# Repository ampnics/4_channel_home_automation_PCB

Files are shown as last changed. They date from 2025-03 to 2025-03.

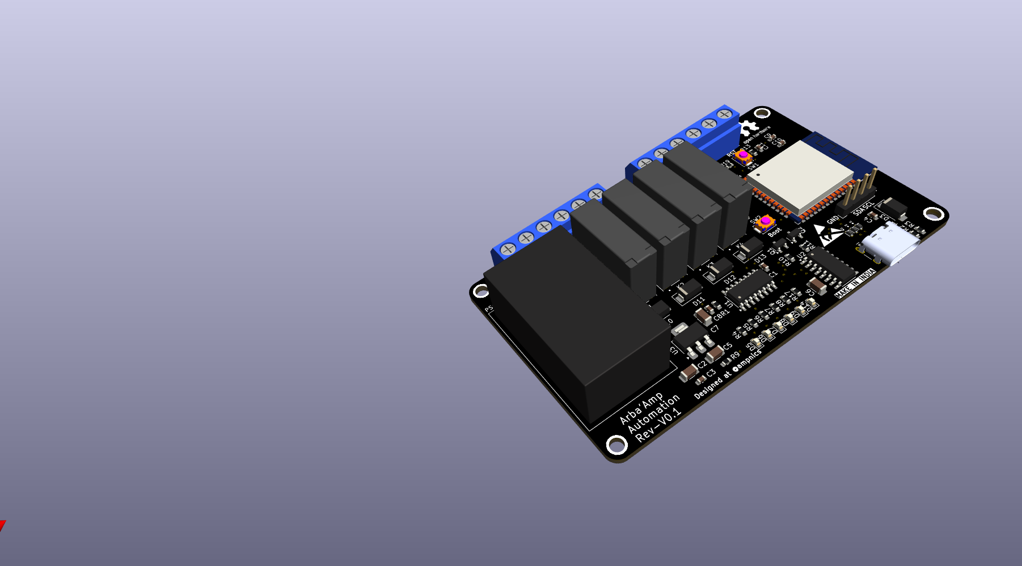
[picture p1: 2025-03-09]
Arbaa_Amp_V0.1/Docs/Img.png

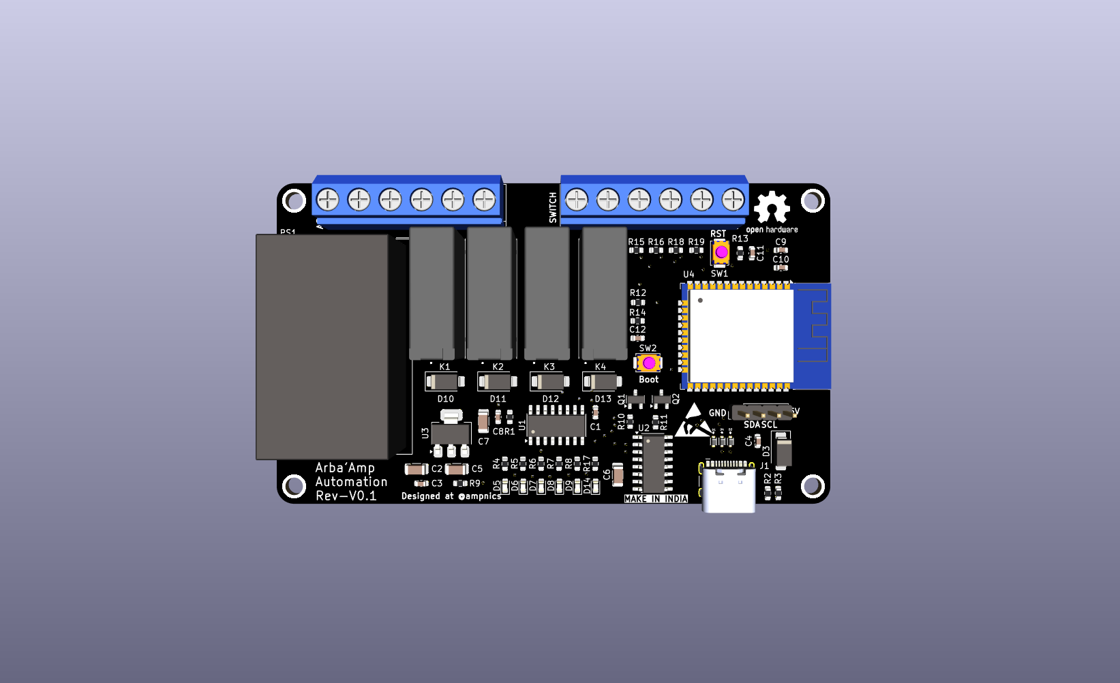
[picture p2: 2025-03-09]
Arbaa_Amp_V0.1/Docs/Top_img.png

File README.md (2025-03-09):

4-Channel Home Automation with ESP32 PCB
This project is a 4-channel home automation system based on the ESP32, designed to control electrical appliances via Wi-Fi, 
MQTT, or a mobile app. The custom PCB integrates relays, optoisolated inputs, and an efficient power supply for reliable operation.

Features

✔ ESP32-based Wi-Fi control (supports web server & MQTT).

✔ 4-Channel relay output for appliance control.

✔ Optoisolated inputs for safe external switch connections.

✔ Onboard buck converter (AC/DC to 5V) for efficient power.

✔ Compact PCB design for easy enclosure integration.

Hardware Overview

1️⃣ Components Used:

ESP32-WROOM-32 (Wi-Fi + Bluetooth MCU)

4 x Relays (5V or 12V, SPDT)

Optocouplers for switch inputs

AC to DC Buck Converter (HLK-PM03 or equivalent)

Screw terminals for easy wiring

Status LEDs for each relay & power indicator

2️⃣ PCB Design Details:

Designed in KiCad

2-layer PCB for cost efficiency

Proper relay isolation from low-voltage ESP32

Wide power traces for relay switching

It is open source design by Md Ammar Maniyar for @ampnics

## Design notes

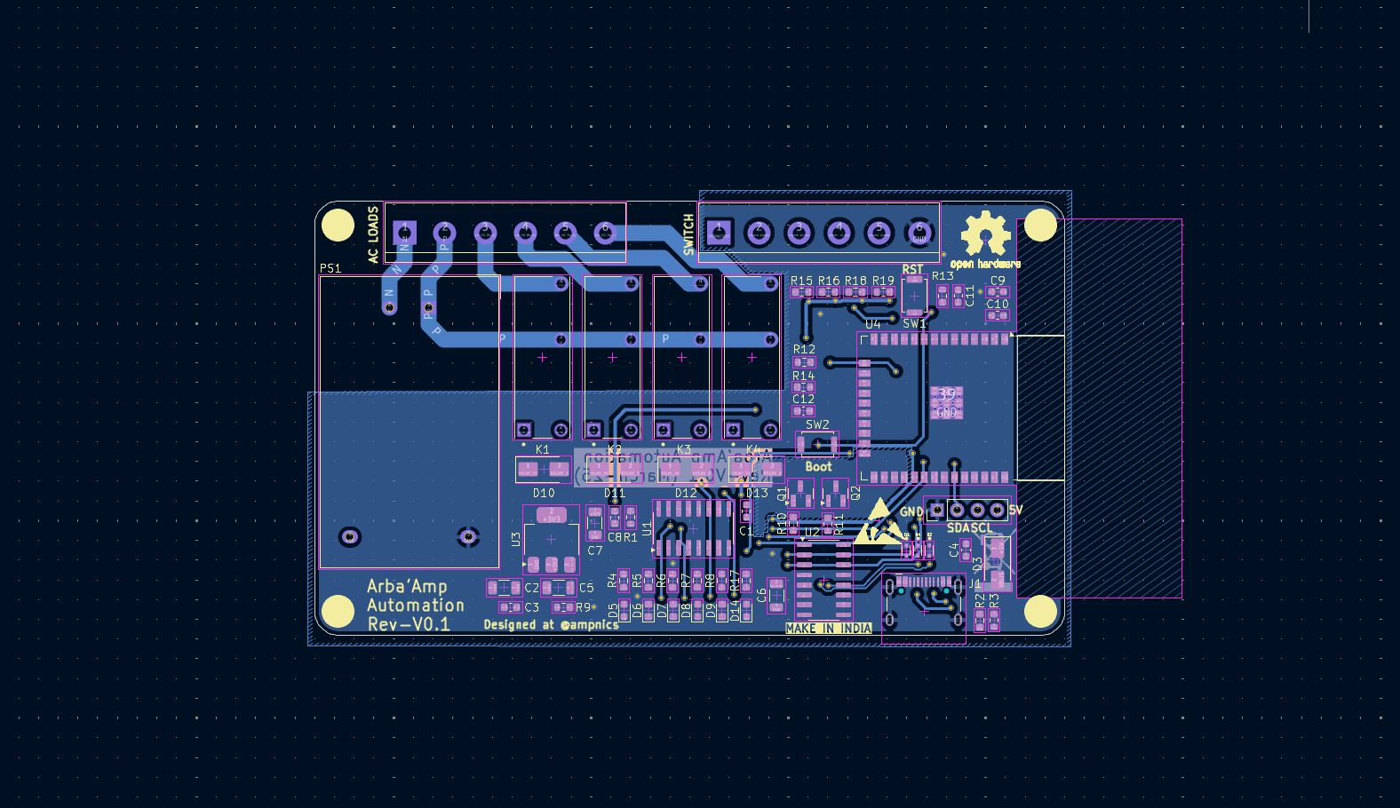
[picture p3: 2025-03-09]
Arbaa_Amp_V0.1/Docs/Bottom_layout.png

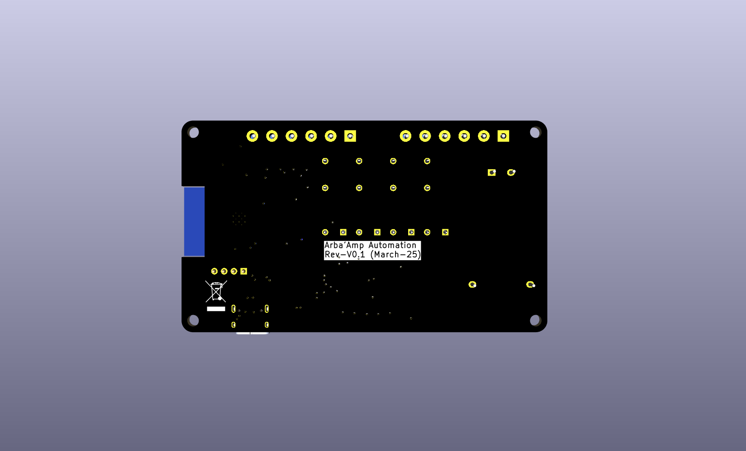
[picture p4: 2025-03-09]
Arbaa_Amp_V0.1/Docs/Bottom_img.png

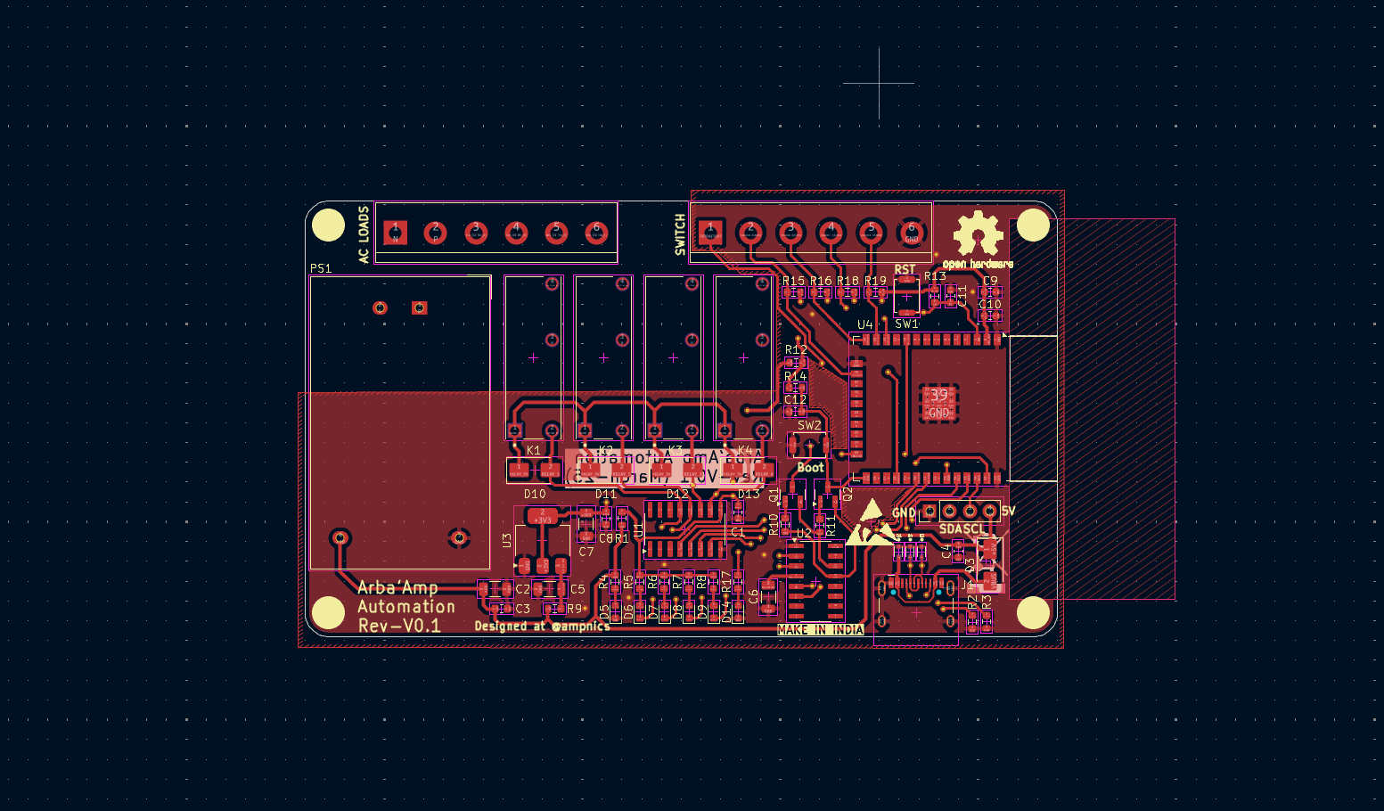
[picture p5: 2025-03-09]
Arbaa_Amp_V0.1/Docs/top_layout.png

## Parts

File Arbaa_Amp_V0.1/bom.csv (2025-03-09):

Reference | Qty | Value | DNP | Exclude from BOM | Exclude from Board | Footprint | Datasheet
C1,C3,C8 | 3 | 0.1uF |  |  |  | Capacitor_SMD:C_0603_1608Metric | ~
C2,C5,C7 | 3 | 10uF |  |  |  | Capacitor_SMD:C_1206_3216Metric | ~
C4 | 1 | 10uF/25V |  |  |  | Capacitor_SMD:C_0603_1608Metric | ~
C6 | 1 | 10nf |  |  |  | Capacitor_SMD:C_1206_3216Metric | ~
C9,C10,C11,C12 | 4 | 0.1uf |  |  |  | Capacitor_SMD:C_0603_1608Metric | ~
D1,D2,D4 | 3 | LESD5D5.0CT1G |  |  |  | LESD5D5.0CT1G:TVS_LESD5D5.0CT1G
D3,D10,D11,D12,D13 | 5 | SS34 |  |  |  | Diode_SMD:D_SMA | https://www.vishay.com/docs/88751/ss32.pdf
D5,D6,D7,D8,D9,D14 | 6 | LED |  |  |  | LED_SMD:LED_0603_1608Metric | ~
J1 | 1 | USB_C_Receptacle_USB2.0_16P |  |  |  | Connector_USB:USB_C_Receptacle_HCTL_HC-TYPE-C-16P-01A | https://www.usb.org/sites/default/files/documents/usb_type-c.zip
J2,J3 | 2 | Screw_Terminal_01x06 |  |  |  | TerminalBlock:TerminalBlock_bornier-6_P5.08mm | ~
J4 | 1 | Conn_01x04_Pin |  |  |  | Connector_PinHeader_2.54mm:PinHeader_1x04_P2.54mm_Vertical | ~
K1,K2,K3,K4 | 4 | HF46F_005-HS1 |  |  |  | HF46F_005-HS1:RELAY_HF46F_005-HS1
PS1 | 1 | HLK-PM01 |  |  |  | Converter_ACDC:Converter_ACDC_Hi-Link_HLK-PMxx | https://h.hlktech.com/download/ACDC%E7%94%B5%E6%BA%90%E6%A8%A1%E5%9D%973W%E7%B3%BB%E5%88%97/1/%E6%B5%B7%E5%87%8C%E7%A7%913W%E7%B3%BB%E5%88%97%E7%94%B5%E6%BA%9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
Q1,Q2 | 2 | SS8050 |  |  |  | Package_TO_SOT_SMD:SOT-23 | http://www.secosgmbh.com/datasheet/products/SSMPTransistor/SOT-23/SS8050.pdf
R1,R9,R12 | 3 | 0E |  |  |  | Resistor_SMD:R_0603_1608Metric | ~
R2,R3 | 2 | 5.1K |  |  |  | Resistor_SMD:R_0603_1608Metric | ~
R4,R5,R6,R7,R8,R17 | 6 | 2K2 |  |  |  | Resistor_SMD:R_0603_1608Metric | ~
R10,R11,R14 | 3 | 10k |  |  |  | Resistor_SMD:R_0603_1608Metric | ~
R13,R15,R16,R18,R19 | 5 | 10K |  |  |  | Resistor_SMD:R_0603_1608Metric | ~
SW1,SW2 | 2 | SW_Push |  |  |  | Button_Switch_SMD:SW_Push_SPST_NO_Alps_SKRK | ~
U1 | 1 | ULN2003A |  |  |  | Package_SO:SOIC-16_3.9x9.9mm_P1.27mm | http://www.ti.com/lit/ds/symlink/uln2003a.pdf
U2 | 1 | CH340C |  |  |  | Package_SO:SOIC-16_3.9x9.9mm_P1.27mm | https://datasheet.lcsc.com/szlcsc/Jiangsu-Qin-Heng-CH340C_C84681.pdf
U3 | 1 | AMS1117-3.3 |  |  |  | Package_TO_SOT_SMD:SOT-223-3_TabPin2 | http://www.advanced-monolithic.com/pdf/ds1117.pdf
U4 | 1 | ESP32-WROOM-32 |  |  |  | RF_Module:ESP32-WROOM-32 | https://www.espressif.com/sites/default/files/documentation/esp32-wroom-32_datasheet_en.pdf

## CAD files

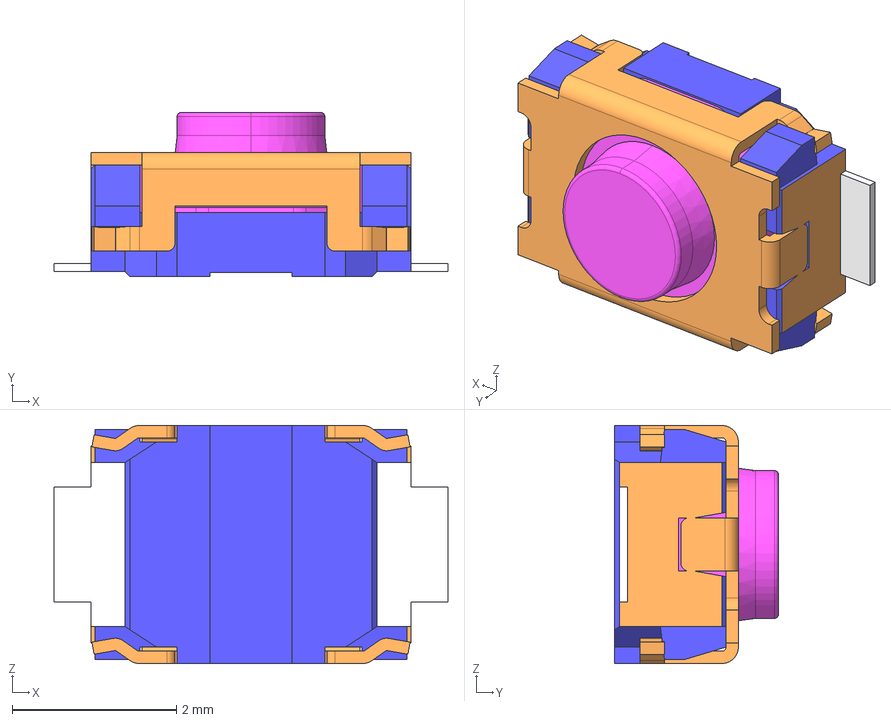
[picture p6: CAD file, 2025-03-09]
Arbaa_Amp_V0.1/External 3D models/skrkaee010.stp
4.80 x 2.00 x 2.90 mm

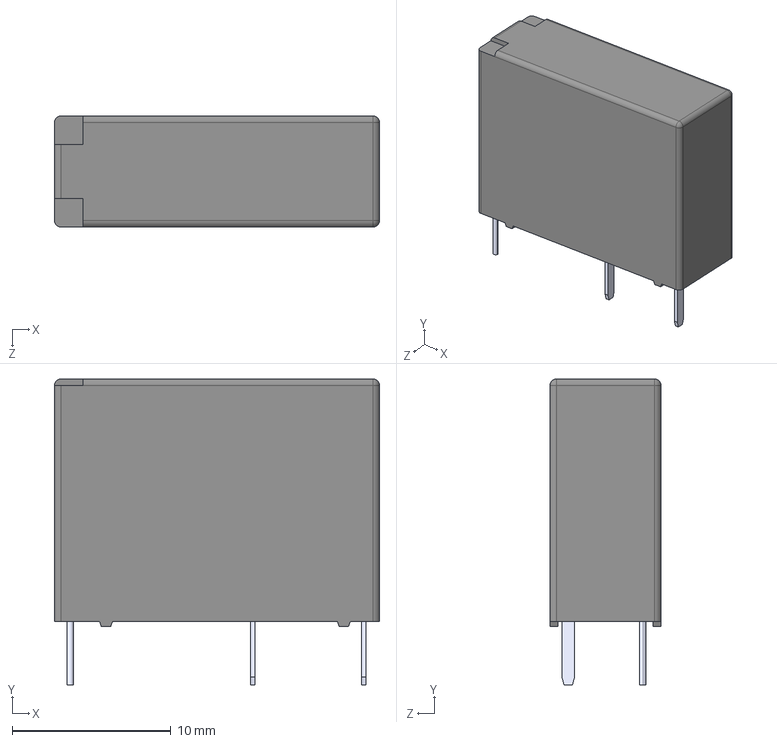
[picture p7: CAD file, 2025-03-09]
Arbaa_Amp_V0.1/External Libraries/HF46F_005-HS1/HF46F_005-HS1.step
20.5 x 19.3 x 7.00 mm

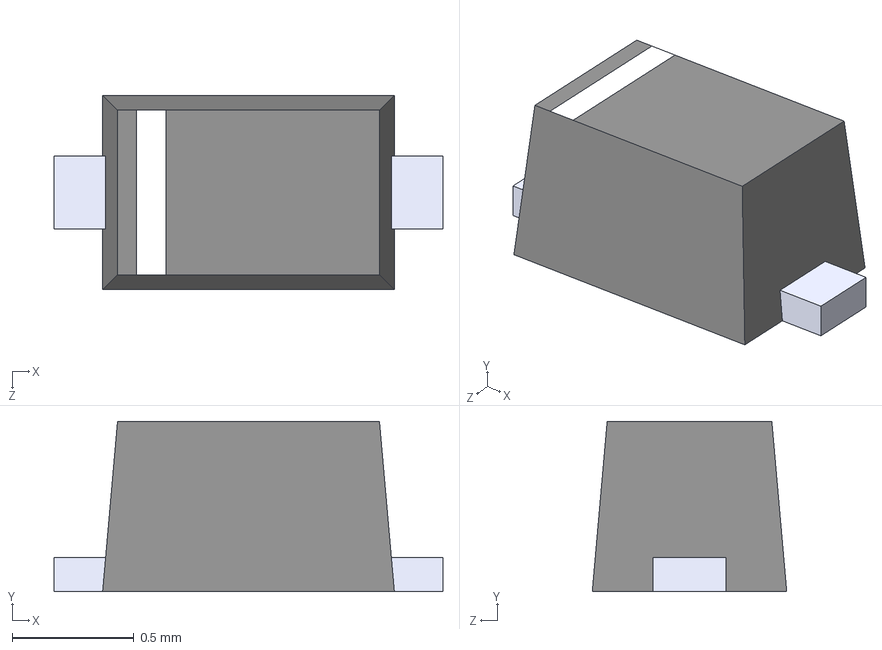
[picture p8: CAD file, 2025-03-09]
Arbaa_Amp_V0.1/External Libraries/LESD5D5.0CT1G/LESD5D5.0CT1G.step
1.60 x 0.7 x 0.8 mm

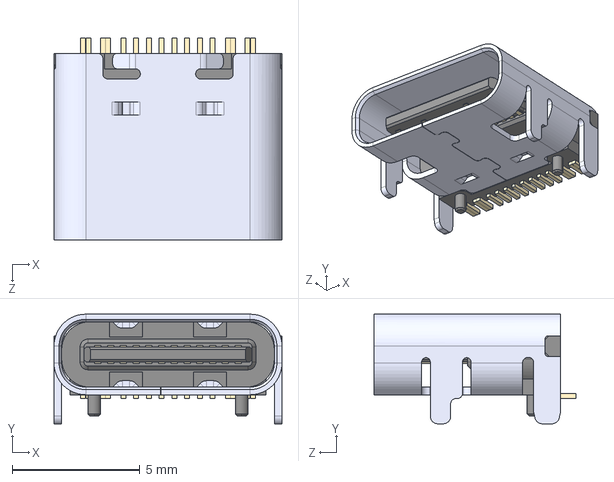
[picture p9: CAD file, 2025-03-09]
Arbaa_Amp_V0.1/External 3D models/TYPE-C-31-M-12--3DModel-STEP-56544.STEP
8.94 x 4.30 x 7.90 mm

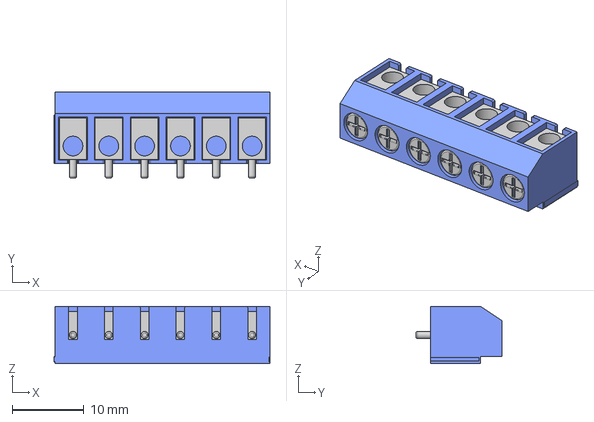
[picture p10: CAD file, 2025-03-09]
Arbaa_Amp_V0.1/External 3D models/Screw Terminal Block 5mm Blue 6-way.step
30.1 x 12.0 x 8.00 mm

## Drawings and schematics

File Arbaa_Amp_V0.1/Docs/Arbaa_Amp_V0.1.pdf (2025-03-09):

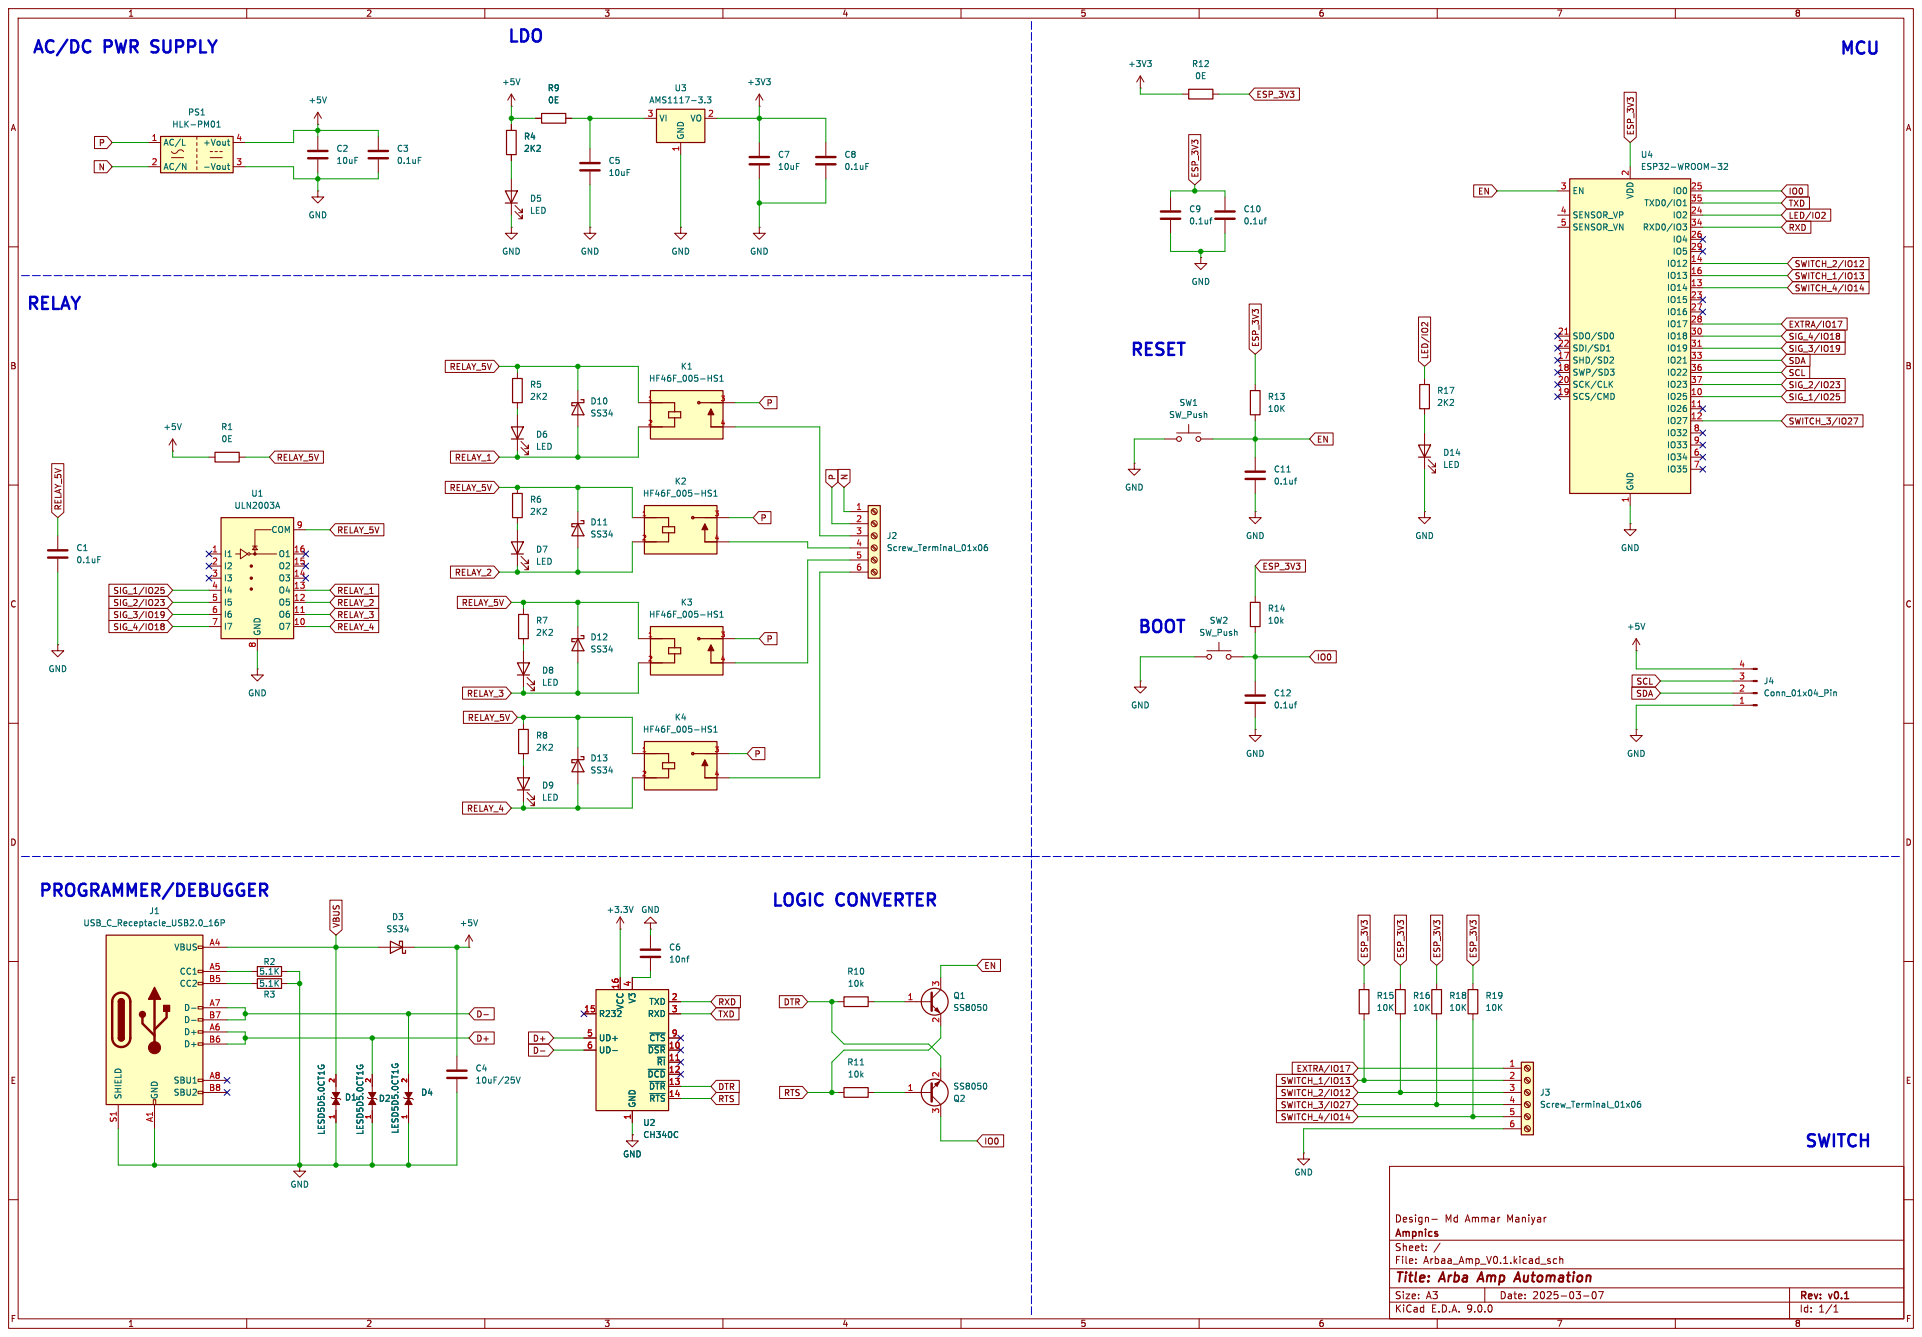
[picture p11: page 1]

AC/DC PWR SUPPLY

1 TXD 2 RXD 3 ~{CTS}9 ~{DSR} 10 ~{RI} 11 ~{DCD} 12 ~{DTR} 13 ~{RTS} 14 GND

1 TXD 2 RXD 3 ~{CTS}9 ~{DSR} 10 ~{RI} 11 ~{DCD} 12 ~{DTR} 13 ~{RTS} 14 U2 CH340C

Id: 1/1 Title: Arba Amp Automation

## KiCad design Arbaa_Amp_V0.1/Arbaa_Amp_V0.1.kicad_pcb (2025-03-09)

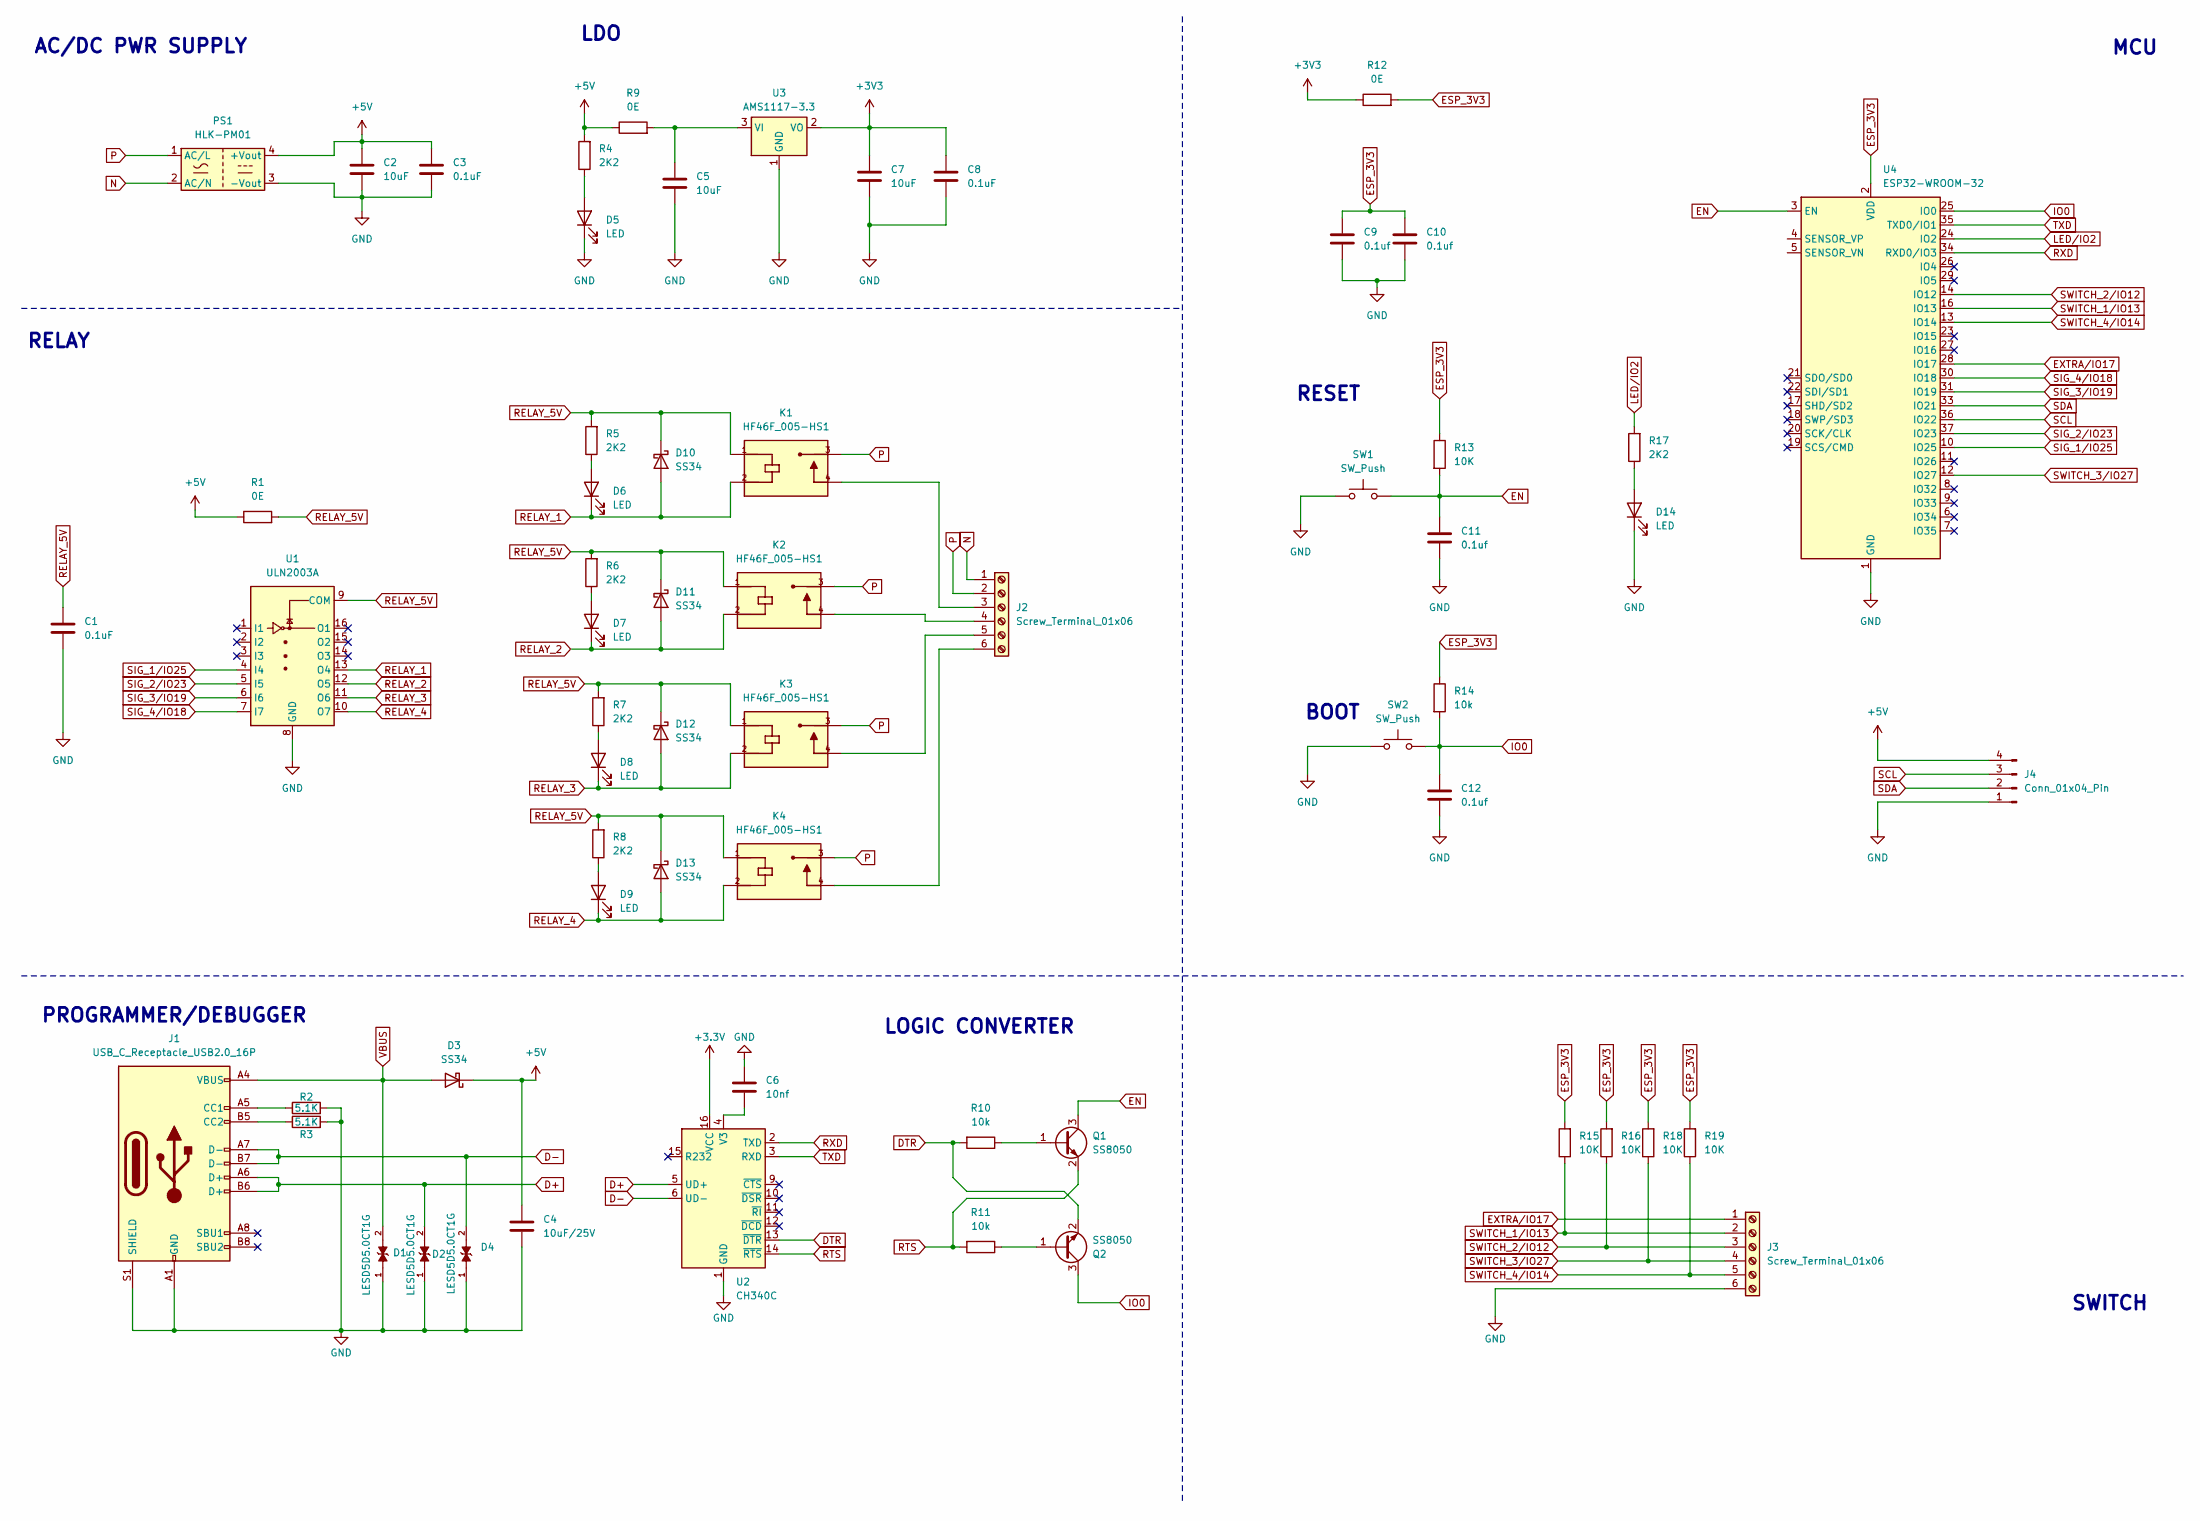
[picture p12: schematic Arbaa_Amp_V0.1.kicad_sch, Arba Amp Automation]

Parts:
C1, C3, C8: 0.1uF; C_0603_1608Metric
C2, C5, C7: 10uF; C_1206_3216Metric
C4: 10uF/25V; C_0603_1608Metric
C6: 10nf; C_1206_3216Metric
C9, C10, C11, C12: 0.1uf; C_0603_1608Metric
D1, D2, D4: LESD5D5.0CT1G; TVS_LESD5D5.0CT1G; PARTREV O
D3, D10, D11, D12, D13: SS34; D_SMA
D5, D6, D7, D8, D9, D14: LED; LED_0603_1608Metric
J1: USB_C_Receptacle_USB2.0_16P; USB_C_Receptacle_HCTL_HC-TYPE-C-16P-01A
J2, J3: Screw_Terminal_01x06; TerminalBlock_bornier-6_P5.08mm
J4: Conn_01x04_Pin; PinHeader_1x04_P2.54mm_Vertical
K1, K2, K3, K4: HF46F_005-HS1; RELAY_HF46F_005-HS1; PARTREV 1.00
PS1: HLK-PM01; Converter_ACDC_Hi-Link_HLK-PMxx
Q1, Q2: SS8050; SOT-23
R1, R9, R12: 0E; R_0603_1608Metric
R2, R3: 5.1K; R_0603_1608Metric
R4, R5, R6, R7, R8, R17: 2K2; R_0603_1608Metric
R10, R11, R14: 10k; R_0603_1608Metric
R13, R15, R16, R18, R19: 10K; R_0603_1608Metric
SW1, SW2: SW_Push; SW_Push_SPST_NO_Alps_SKRK
U1: ULN2003A; SOIC-16_3.9x9.9mm_P1.27mm
U2: CH340C; SOIC-16_3.9x9.9mm_P1.27mm
U3: AMS1117-3.3; SOT-223-3_TabPin2
U4: ESP32-WROOM-32

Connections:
+3.3V: U2.16 (VCC)
+3V3: C7.1, C8.1, R12.1, U3.2 (VO)
+5V: C2.1, C3.1, C4.1, D3.1 (K), J4.4, PS1.4 (+Vout), R1.1, R4.2, R9.1
D+: D2.2, J1.A6 (D+), J1.B6 (D+), U2.5 (UD+)
D-: D4.2, J1.A7 (D-), J1.B7 (D-), U2.6 (UD-)
DTR: Q2.2 (E), R10.2, U2.13 (~DTR)
EN: C11.1, Q1.3 (C), R13.2, SW1.2, U4.3 (EN)
ESP_3V3: C9.1, C10.1, R12.2, R13.1, R14.1, R15.2, R16.2, R18.2, R19.2, U4.2 (VDD)
EXTRA/IO17: J3.1, U4.28 (IO17)
GND: C1.2, C2.2, C3.2, C4.2, C5.2, C6.1, C7.2, C8.2, C9.2, C10.2, C11.2, C12.2, D1.1, D2.1, D4.1, D5.1 (K), D14.1 (K), J1.A1 (GND), J1.A12 (GND), J1.B1 (GND), J1.B12 (GND), J1.S1 (SHIELD), J3.6, J4.1, PS1.3 (-Vout), R2.2, R3.2, SW1.1, SW2.1, U1.8 (GND), U2.1 (GND), U3.1 (GND), U4.1 (GND), U4.15 (GND), U4.38 (GND), U4.39 (GND)
IO0: C12.1, Q2.3 (C), R14.2, SW2.2, U4.25 (IO0)
LED/IO2: R17.2, U4.24 (IO2)
N: J2.1, PS1.2 (AC/N)
unnamed: D5.2 (A), R4.1
unnamed: D6.2 (A), R5.1
unnamed: D7.2 (A), R6.1
unnamed: D8.2 (A), R7.1
unnamed: D9.2 (A), R8.1
unnamed: D14.2 (A), R17.1
unnamed: J1.A5 (CC1), R2.1
unnamed: J1.B5 (CC2), R3.1
unnamed: J2.3, K1.4
unnamed: J2.4, K2.4
unnamed: J2.5, K3.4
unnamed: J2.6, K4.4
unnamed: Q1.1 (B), R10.1
unnamed: Q2.1 (B), R11.1
unnamed: C6.2, U2.4 (V3)
unnamed: C5.1, R9.2, U3.3 (VI)
P: J2.2, K1.3, K2.3, K3.3, K4.3, PS1.1 (AC/L)
RELAY_1: D6.1 (K), D10.2 (A), K1.2, U1.13 (O4)
RELAY_2: D7.1 (K), D11.2 (A), K2.2, U1.12 (O5)
RELAY_3: D8.1 (K), D12.2 (A), K3.2, U1.11 (O6)
RELAY_4: D9.1 (K), D13.2 (A), K4.2, U1.10 (O7)
RELAY_5V: C1.1, D10.1 (K), D11.1 (K), D12.1 (K), D13.1 (K), K1.1, K2.1, K3.1, K4.1, R1.2, R5.2, R6.2, R7.2, R8.2, U1.9 (COM)
RTS: Q1.2 (E), R11.2, U2.14 (~RTS)
RXD: U2.2 (TXD), U4.34 (RXD0/IO3)
SCL: J4.3, U4.36 (IO22)
SDA: J4.2, U4.33 (IO21)
SIG_1/IO25: U1.4 (I4), U4.10 (IO25)
SIG_2/IO23: U1.5 (I5), U4.37 (IO23)
SIG_3/IO19: U1.6 (I6), U4.31 (IO19)
SIG_4/IO18: U1.7 (I7), U4.30 (IO18)
SWITCH_1/IO13: J3.2, R15.1, U4.16 (IO13)
SWITCH_2/IO12: J3.3, R16.1, U4.14 (IO12)
SWITCH_3/IO27: J3.4, R18.1, U4.12 (IO27)
SWITCH_4/IO14: J3.5, R19.1, U4.13 (IO14)
TXD: U2.3 (RXD), U4.35 (TXD0/IO1)
VBUS: D1.2, D3.2 (A), J1.A4 (VBUS), J1.A9 (VBUS), J1.B4 (VBUS), J1.B9 (VBUS)

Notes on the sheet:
SWITCH
MCU
PROGRAMMER/DEBUGGER
LOGIC CONVERTER
RESET
BOOT
LDO
RELAY
AC/DC PWR SUPPLY

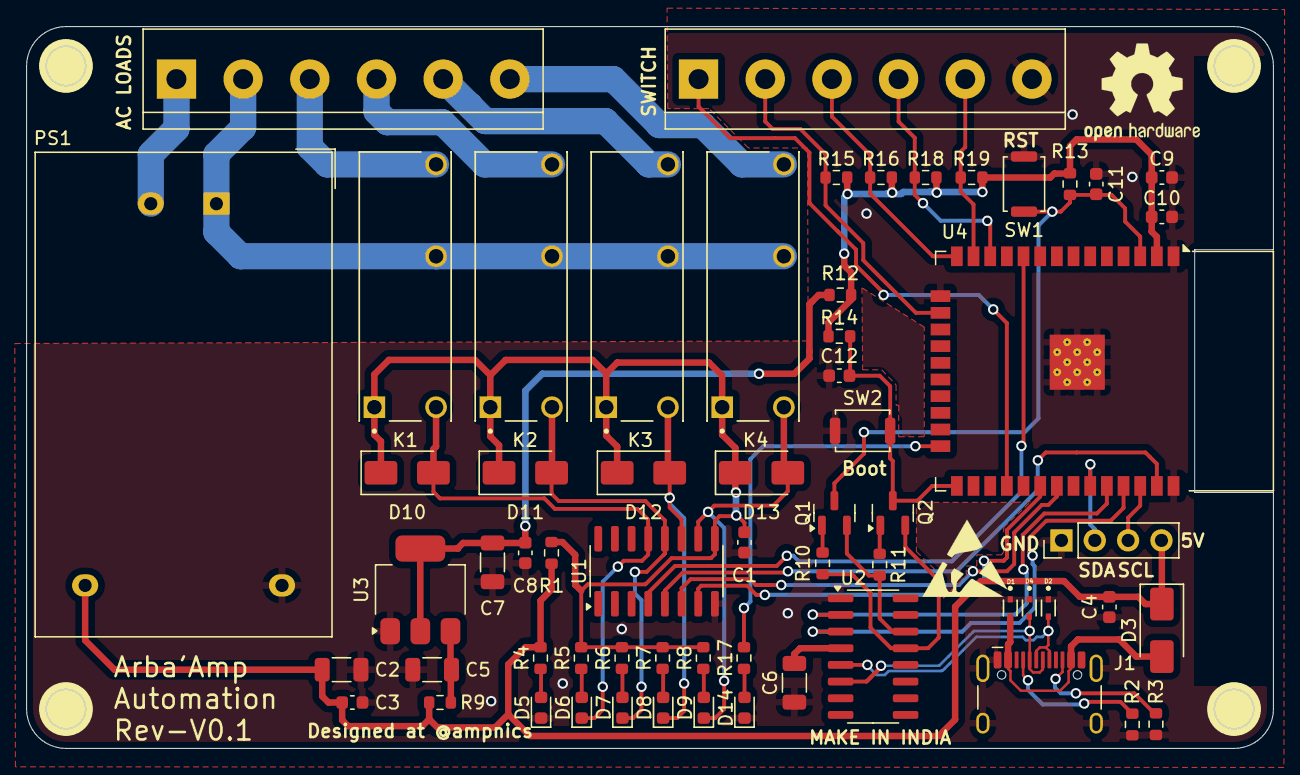
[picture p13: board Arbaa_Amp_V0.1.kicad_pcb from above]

Board: 2 copper layers, 95.0 x 55.0 mm, 62 parts (0 on the bottom side), 48 nets.
